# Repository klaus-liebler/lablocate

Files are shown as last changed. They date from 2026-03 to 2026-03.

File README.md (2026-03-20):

# Lieblers LabLocate



## Components 
- Quovo DWM3000 ist ein UWB-Ortungsmodul (UltaWideBand_ige Funkwellen lassen sich gut hinsichtlich Signallaufzeit vermessen)
- ESP32-C6: Mikrocontroller mit 2.4 GHz Wi-Fi 6 (802.11ax), Bluetooth® 5 (LE), Zigbee and Thread (802.15.4)
- LSM6DS3 ist ein 6DOF-Beschleunigungssensor
- TPS63802 ist ein StepUp-Step-Down-Converter
- TP4057 ist ein Batterie-Lade-ID

## Recommendations
- Needs https://github.com/klaus-liebler/kicad-libs
- Recommended PCB Software: [https://www.kicad.org](https://www.kicad.org/)
- Recommended PCBA Service: https://jlcpcb.com/
- Recommended Kicad-Plugin for JLCPCB: https://github.com/Bouni/kicad-jlcpcb-tools
- Check this Software for UWB Locating: https://github.com/jremington/UWB-Indoor-Localization_Arduino

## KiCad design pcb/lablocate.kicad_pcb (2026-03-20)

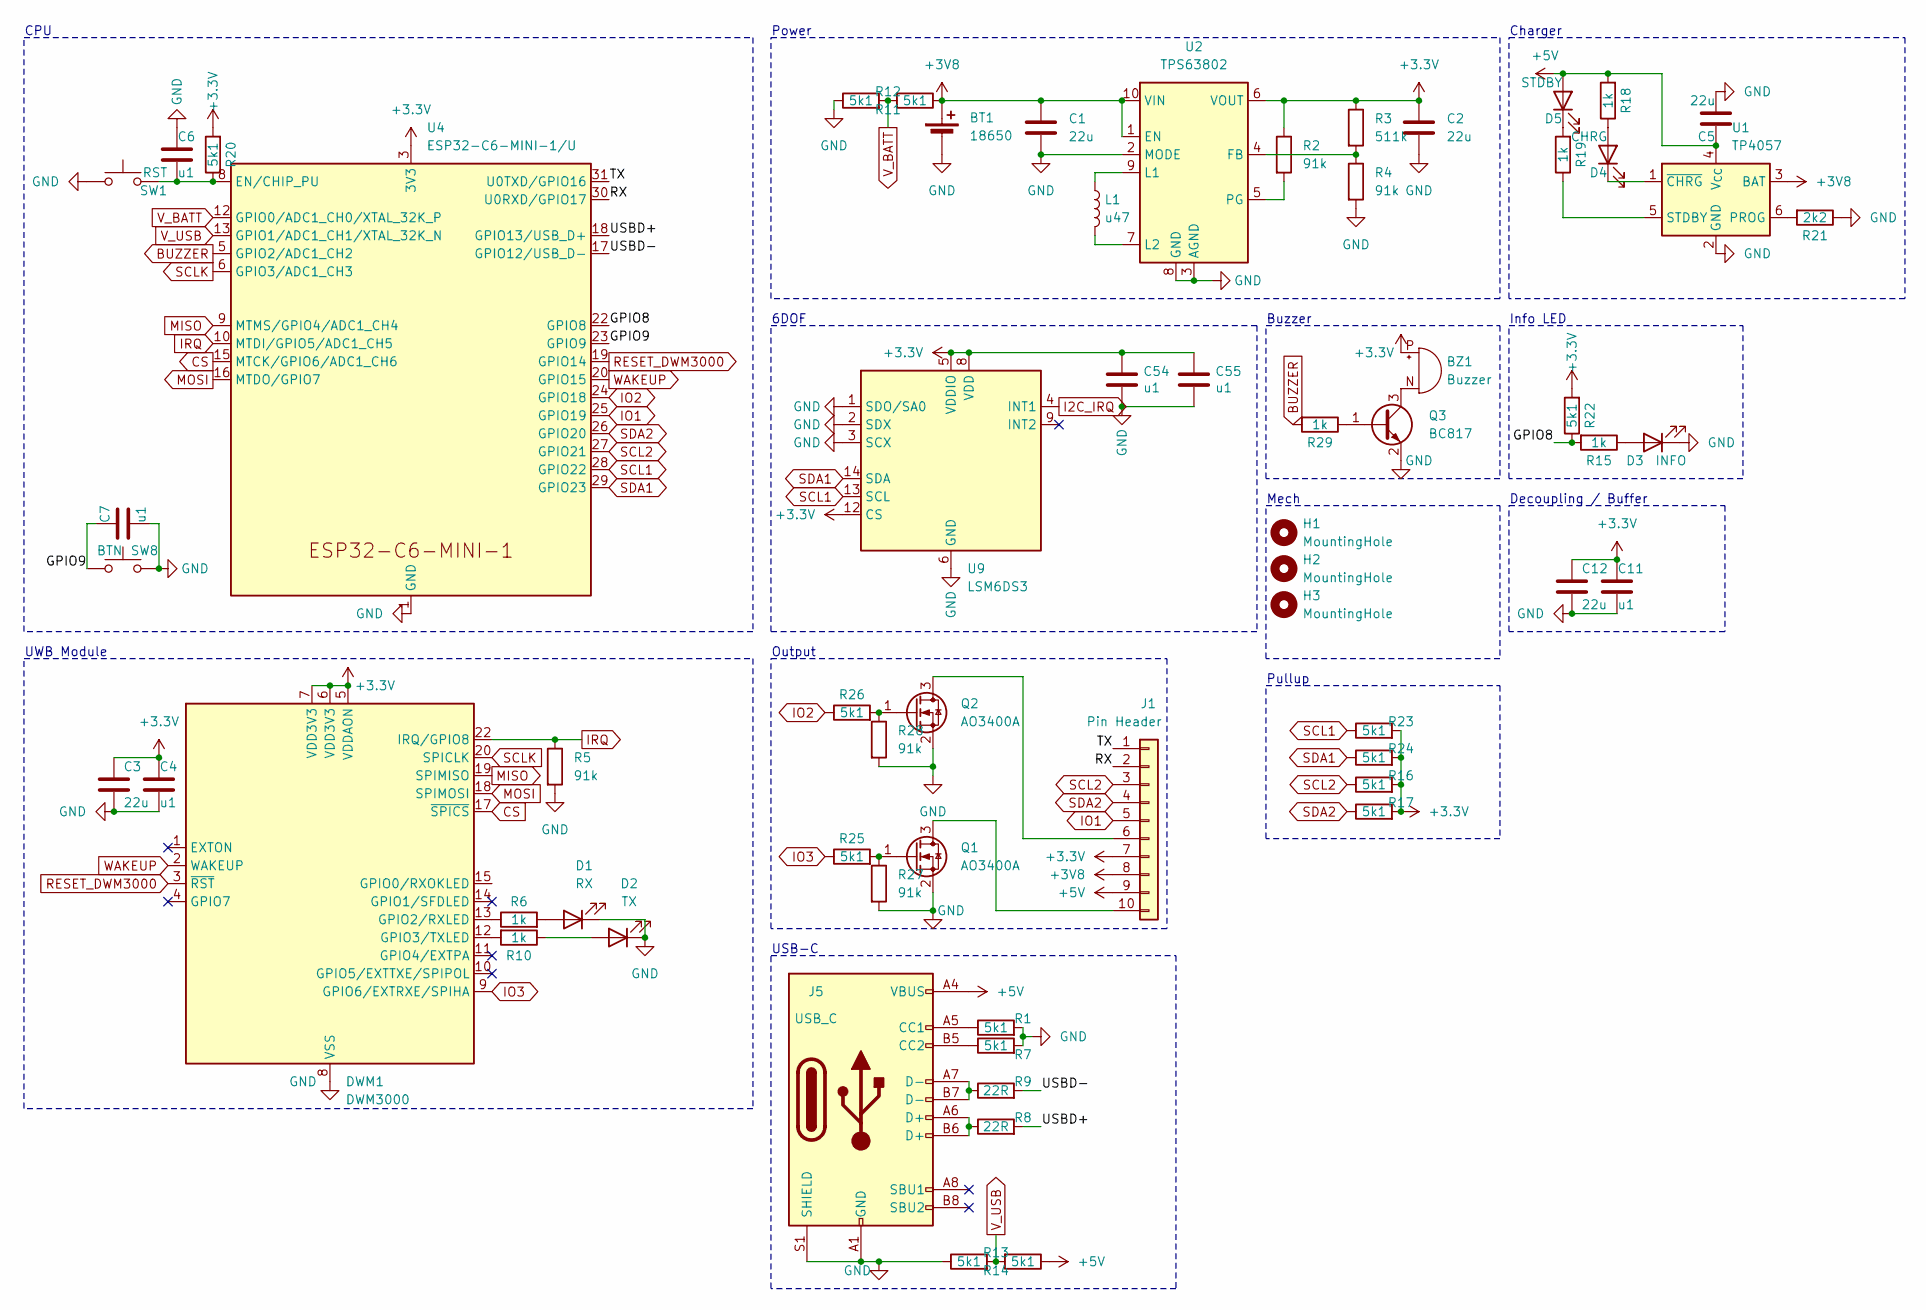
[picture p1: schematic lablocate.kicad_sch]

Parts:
BT1: 18650; BatteryHolder_MPD_BH-18650-PC2
BZ1: Buzzer; XDCR_CMT-7525-80-SMT-TR_handsolder
C1, C2, C3, C5, C12: 22u; C_0603_1608Metric
C4, C6, C7, C11: u1; C_0201_0603Metric
C54, C55: u1; C_0201_0603Metric; MPN GRM033R61A104KE15D
D1: RX; LED_0402_1005Metric
D2: TX; LED_0402_1005Metric
D3: INFO; LED_0402_1005Metric
D4: CHRG; LED_0402_1005Metric
D5: STDBY; LED_0402_1005Metric
DWM1: DWM3000; DWM1000
H1, H2, H3: MountingHole; MountingHole_2.2mm_M2
J1: Pin Header; PinHeader_1x10_P2.54mm_Vertical
J5: USB_C; USB_C_Receptacle_HRO_TYPE-C-31-M-12
L1: u47; L_Changjiang_FTC252012S
Q1, Q2: AO3400A; SOT-23
Q3: BC817; SOT-23
R1, R7, R11, R12, R13, R14, R16, R17, R20, R22, R23, R24, R25, R26: 5k1; R_0201_0603Metric
R2, R4, R5, R27, R28: 91k; R_0201_0603Metric
R3: 511k; R_0201_0603Metric
R6, R10, R15, R18, R19, R29: 1k; R_0402_1005Metric
R8, R9: 22R; R_0402_1005Metric
R21: 2k2; R_0402_1005Metric
SW1: RST; SW_SPST_B3U-1000P; MPN TS-1095E-A6B3-D2
SW8: BTN; SW_SPST_B3U-1000P; MPN TS-1095E-A6B3-D2
U1: TP4057; TSOT-23-6
U2: TPS63802; DLA0010A
U4: ESP32-C6-MINI-1/U; ESP32-C6-MINI-1
U9: LSM6DS3; LGA-14_3x2.5mm_P0.5mm_LayoutBorder3x4y; MPN LSM6DS3TR-C

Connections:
+3.3V: BZ1.P (+), C2.1, C3.1, C4.1, C11.1, C12.1, C54.2, C55.2, DWM1.5 (VDDAON), DWM1.6 (VDD3V3), DWM1.7 (VDD3V3), J1.7, R2.1, R3.1, R16.2, R17.2, R20.2, R22.2, R23.2, R24.2, U2.6 (VOUT), U4.3 (3V3), U9.5 (VDDIO), U9.8 (VDD), U9.12 (CS)
+3V8: BT1.1 (+), C1.1, J1.8, R12.1, U1.3 (BAT), U2.1 (EN), U2.10 (VIN)
+5V: C5.1, D5.2 (A), J1.9, J5.A4 (VBUS), J5.A9 (VBUS), J5.B4 (VBUS), J5.B9 (VBUS), R13.1, R18.2, U1.4 (V_{CC})
/GPIO8: R15.2, R22.1, U4.22 (GPIO8)
/GPIO9: C7.1, SW8.1, U4.23 (GPIO9)
/RX: J1.2, U4.30 (U0RXD/GPIO17)
/TX: J1.1, U4.31 (U0TXD/GPIO16)
/USBD+: R8.2, U4.18 (GPIO13/USB_D+)
/USBD-: R9.2, U4.17 (GPIO12/USB_D-)
BUZZER: R29.2, U4.5 (GPIO2/ADC1_CH2)
CS: DWM1.17 (~SPICS), U4.15 (MTCK/GPIO6/ADC1_CH6)
GND: BT1.2 (-), C1.2, C2.2, C3.2, C4.2, C5.2, C6.1, C7.2, C11.2, C12.2, C54.1, C55.1, D1.1 (K), D2.1 (K), D3.1 (K), DWM1.8 (VSS), DWM1.16 (VSS), DWM1.21 (VSS), DWM1.23 (VSS), DWM1.24 (VSS), J5.A1 (GND), J5.A12 (GND), J5.B1 (GND), J5.B12 (GND), J5.S1 (SHIELD), Q1.2 (S), Q2.2 (S), Q3.2 (E), R1.2, R4.2, R5.2, R7.2, R11.1, R14.1, R21.1, R27.2, R28.2, SW1.1, SW8.2, U1.2 (GND), U2.2 (MODE), U2.3 (AGND), U2.8 (GND), U4.1 (GND), U4.2 (GND), U4.11 (GND), U4.14 (GND), U4.36 (GND), U4.37 (GND), U4.38 (GND), U4.39 (GND), U4.40 (GND), U4.41 (GND), U4.42 (GND), U4.43 (GND), U4.44 (GND), U4.45 (GND), U4.46 (GND), U4.47 (GND), U4.48 (GND), U4.49 (GND), U4.50 (GND), U4.51 (GND), U4.52 (GND), U4.53 (GND), U9.1 (SDO/SA0), U9.2 (SDX), U9.3 (SCX), U9.6 (GND), U9.7 (GND)
I2C_IRQ: U9.4 (INT1)
IO1: J1.5, U4.25 (GPIO19)
IO2: R26.1, U4.24 (GPIO18)
IO3: DWM1.9 (GPIO6/EXTRXE/SPIHA), R25.1
IRQ: DWM1.22 (IRQ/GPIO8), R5.1, U4.10 (MTDI/GPIO5/ADC1_CH5)
MISO: DWM1.19 (SPIMISO), U4.9 (MTMS/GPIO4/ADC1_CH4)
MOSI: DWM1.18 (SPIMOSI), U4.16 (MTDO/GPIO7)
unnamed: BZ1.N (-), Q3.3 (C)
unnamed: D1.2 (A), R6.2
unnamed: D2.2 (A), R10.1
unnamed: D3.2 (A), R15.1
unnamed: D4.2 (A), R18.1
unnamed: D4.1 (K), U1.1 (~CHRG)
unnamed: D5.1 (K), R19.2
unnamed: DWM1.13 (GPIO2/RXLED), R6.1
unnamed: DWM1.12 (GPIO3/TXLED), R10.2
unnamed: J1.6, Q2.3 (D)
unnamed: J1.10, Q1.3 (D)
unnamed: J5.A5 (CC1), R1.1
unnamed: J5.B5 (CC2), R7.1
unnamed: J5.A6 (D+), J5.B6 (D+), R8.1
unnamed: J5.A7 (D-), J5.B7 (D-), R9.1
unnamed: Q1.1 (G), R25.2, R27.1
unnamed: Q2.1 (G), R26.2, R28.1
unnamed: Q3.1 (B), R29.1
unnamed: R21.2, U1.6 (PROG)
unnamed: R19.1, U1.5 (STDBY)
unnamed: R3.2, R4.1, U2.4 (FB)
unnamed: L1.1, U2.9 (L1)
unnamed: L1.2, U2.7 (L2)
unnamed: R2.2, U2.5 (PG)
unnamed: C6.2, R20.1, SW1.2, U4.8 (EN/CHIP_PU)
RESET_DWM3000: DWM1.3 (~RST), U4.19 (GPIO14)
SCL1: R23.1, U4.28 (GPIO22), U9.13 (SCL)
SCL2: J1.3, R16.1, U4.27 (GPIO21)
SCLK: DWM1.20 (SPICLK), U4.6 (GPIO3/ADC1_CH3)
SDA1: R24.1, U4.29 (GPIO23), U9.14 (SDA)
SDA2: J1.4, R17.1, U4.26 (GPIO20)
V_BATT: R11.2, R12.2, U4.12 (GPIO0/ADC1_CH0/XTAL_32K_P)
V_USB: R13.2, R14.2, U4.13 (GPIO1/ADC1_CH1/XTAL_32K_N)
WAKEUP: DWM1.2 (WAKEUP), U4.20 (GPIO15)

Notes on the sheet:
Buzzer
Info LED
6DOF
Decoupling / Buffer
Output
Charger
Pullup
CPU
Mech
UWB Module
Power
USB-C

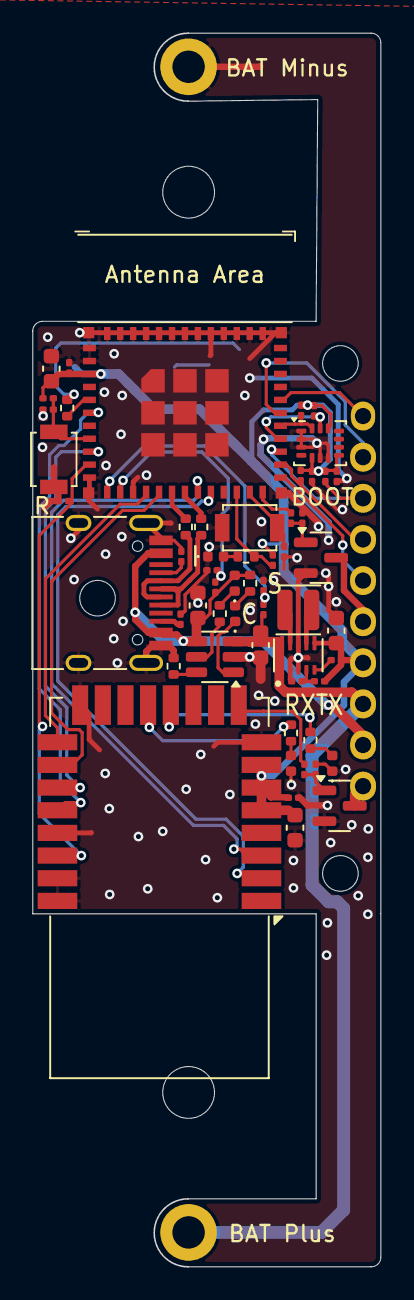
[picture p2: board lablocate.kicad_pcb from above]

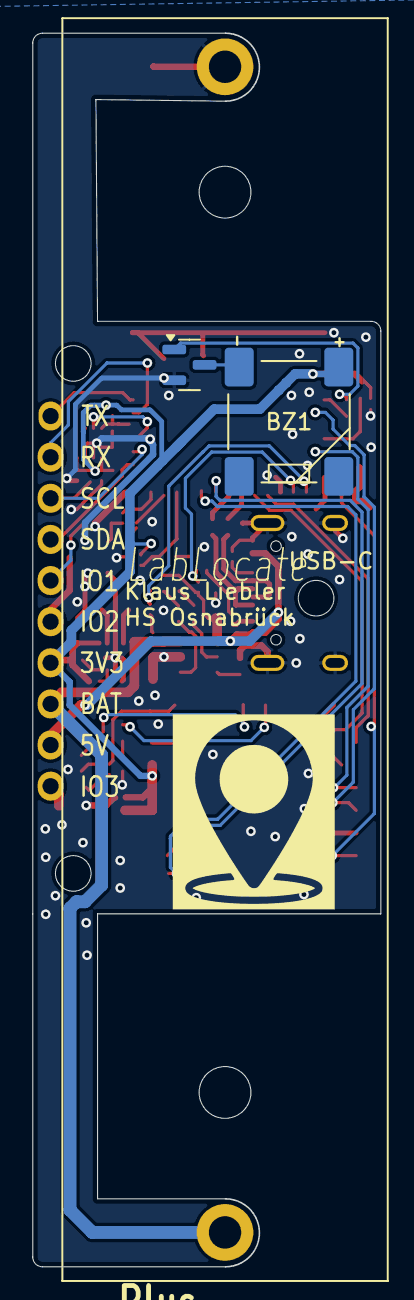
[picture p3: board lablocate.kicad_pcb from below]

Board: 2 copper layers, 21.5 x 76.2 mm, 63 parts (5 on the bottom side), 52 nets.
